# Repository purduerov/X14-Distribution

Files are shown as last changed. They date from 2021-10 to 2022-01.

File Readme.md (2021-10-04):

# Readme for X14-Distribution

Whenever you make a new part, download the datasheet and save it here _**and**_ with the part in the parts library

Always pull other people's changes before beginning to work
`git pull`

Be sure to push your changes after  working on them. Run:
1. `git add .` to add any files in this directory or a subdirectory
or `git add -u` to add any modified files
2. (Optional) `git clean -nX` to see what ignored files can be removed
	`git clean -fX` removes ignored files (Eagle backups)
3. `git commit -m "helpful commit message"` with a description of the work that you did
4. `git push` to push your work to github

Other helpful commands
* `git status` says information about modified and staged files
* `git log` shows the recent commits of the repository
* `git log filename.extension` show the recent commits for just that file
* `git checkout first-couple-letter-of-commit-id` lets you go back to a previous version
* `git checkout master` brings you back to the latest commit
* `git tag` lists the tags
* `git tag -a orderX -m "the version of the board placed for the X'th order"` tag a specific commit
* `git push --tags` needed to push tags to remote
* `git show orderX` show the commit log for the given tag
* `git checkout orderX` go back and interact with the files at the tagged commit

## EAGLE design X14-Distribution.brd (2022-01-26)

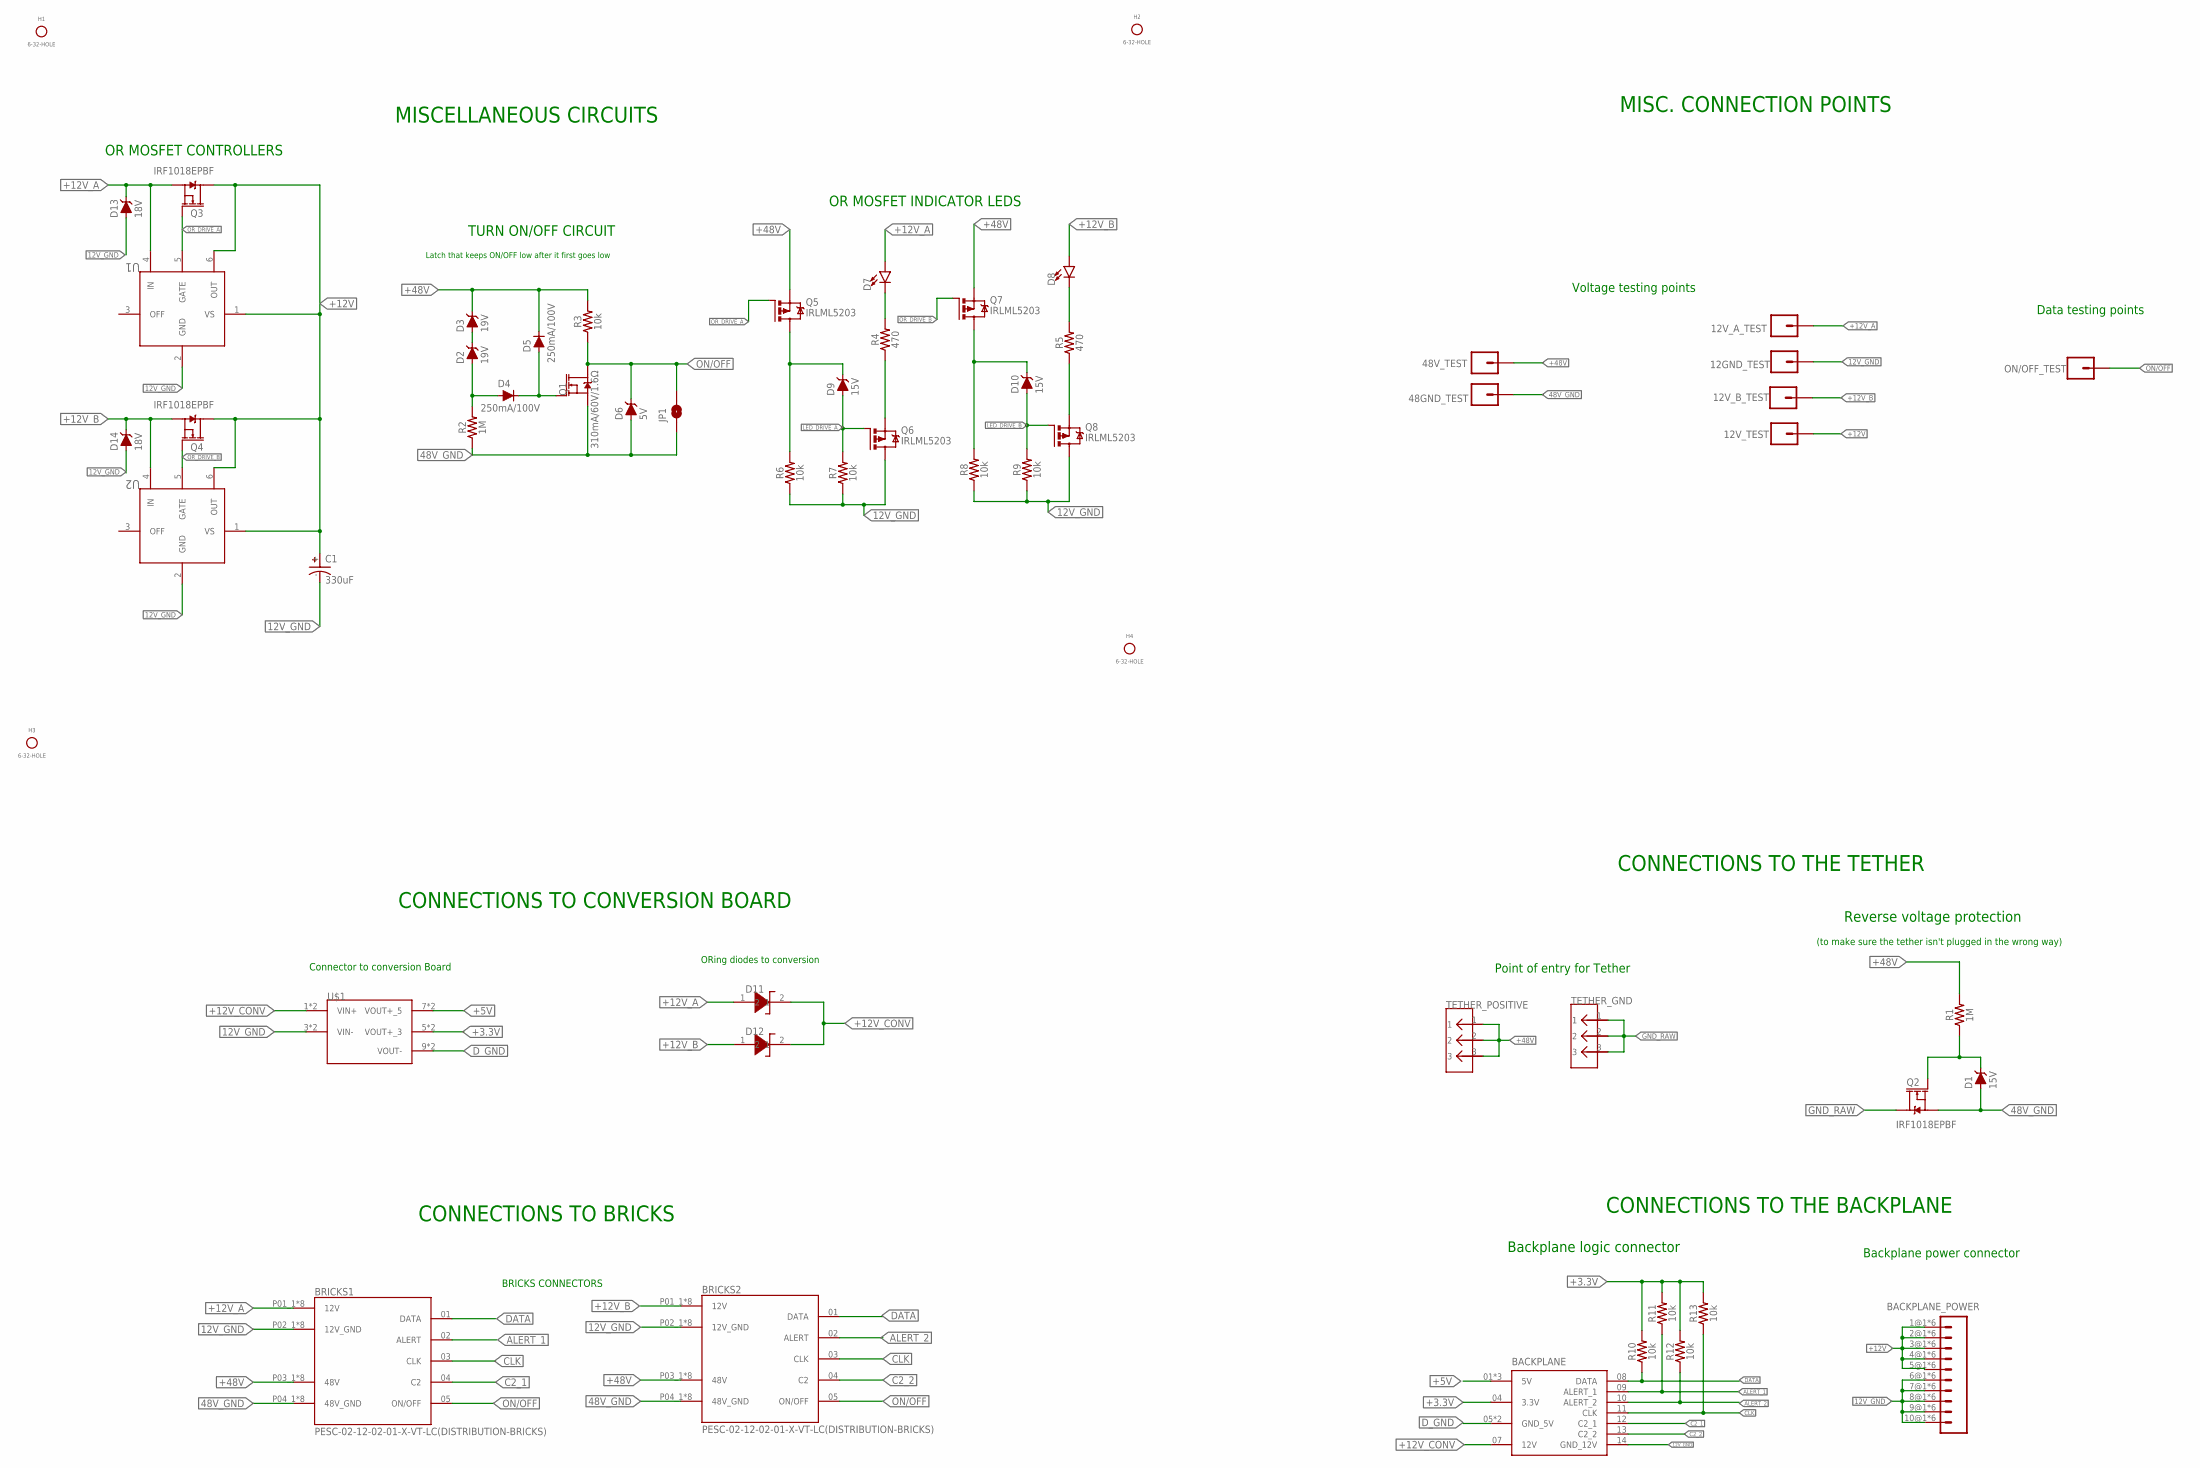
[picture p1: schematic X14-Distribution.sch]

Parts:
12GND_TEST, 12V_A_TEST, 12V_B_TEST, 12V_TEST, 48GND_TEST, 48V_TEST: CONN_01; 1X01
BACKPLANE: DISTRIBUTION-BACKPLANE; SAMTEC_IPL1-107-01-X-D-K(D-B)
BACKPLANE_POWER: MPPT-10-01-01-L-RA-SD
BRICKS1, BRICKS2: PESC-02-12-02-01-X-VT-LC(DISTRIBUTION-BRICKS); SAMTEC_PESC-02-12-02-01-X-VT-LC(D-B)
C1: 330uF; CAPAE1030X1050N
D1, D9, D10: 15V; SOD-323
D2, D3: 19V; SOD-323
D4, D5: 250mA/100V; SOD-323
D6: 5V; SOD-323
D7, D8: LED0603; LED-0603
D11, D12: DIODE-DO-214AC(SK34ATR)
D13, D14: 18V; PANASONIC_SMINI2-F5-B
H1, H2, H3, H4: 6-32-HOLE
JP1: JUMPER-SMT_2_NO_SILK; SMT-JUMPER_2_NO_SILK
ON/OFF_TEST: CONN_01; 1X01
Q1: 310mA/60V/1.6Ω; SOT323
Q2, Q3, Q4: IRF1018EPBF; TO263
Q5, Q6, Q7, Q8: IRLML5203; SOT23
R1, R2: 1M; 0603
R3, R6, R7, R8, R9, R10, R11, R12, R13: 10k; 0603
R4, R5: 470; 0603
TETHER_GND: 796636-3
TETHER_POSITIVE: 796636-3
U1, U2: DIST_OR_CONTROL_ALTMK06A-M; SOT-23-6
U$1: DISTRIBUTION-CONVERSION; TSW-105-05-G-S(D-C)

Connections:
12V_GND: 12GND_TEST.1, BACKPLANE.14 (GND_12V), BACKPLANE_POWER.6@1 (6), BACKPLANE_POWER.6@2 (6), BACKPLANE_POWER.6@3 (6), BACKPLANE_POWER.6@4 (6), BACKPLANE_POWER.6@5 (6), BACKPLANE_POWER.6@6 (6), BACKPLANE_POWER.7@1 (7), BACKPLANE_POWER.7@2 (7), BACKPLANE_POWER.7@3 (7), BACKPLANE_POWER.7@4 (7), BACKPLANE_POWER.7@5 (7), BACKPLANE_POWER.7@6 (7), BACKPLANE_POWER.8@1 (8), BACKPLANE_POWER.8@2 (8), BACKPLANE_POWER.8@3 (8), BACKPLANE_POWER.8@4 (8), BACKPLANE_POWER.8@5 (8), BACKPLANE_POWER.8@6 (8), BACKPLANE_POWER.9@1 (9), BACKPLANE_POWER.9@2 (9), BACKPLANE_POWER.9@3 (9), BACKPLANE_POWER.9@4 (9), BACKPLANE_POWER.9@5 (9), BACKPLANE_POWER.9@6 (9), BACKPLANE_POWER.10@1 (10), BACKPLANE_POWER.10@2 (10), BACKPLANE_POWER.10@3 (10), BACKPLANE_POWER.10@4 (10), BACKPLANE_POWER.10@5 (10), BACKPLANE_POWER.10@6 (10), BRICKS1.P02_1 (12V_GND), BRICKS1.P02_2 (12V_GND), BRICKS1.P02_3 (12V_GND), BRICKS1.P02_4 (12V_GND), BRICKS1.P02_5 (12V_GND), BRICKS1.P02_6 (12V_GND), BRICKS1.P02_7 (12V_GND), BRICKS1.P02_8 (12V_GND), BRICKS2.P02_1 (12V_GND), BRICKS2.P02_2 (12V_GND), BRICKS2.P02_3 (12V_GND), BRICKS2.P02_4 (12V_GND), BRICKS2.P02_5 (12V_GND), BRICKS2.P02_6 (12V_GND), BRICKS2.P02_7 (12V_GND), BRICKS2.P02_8 (12V_GND), C1.-, D13.A, D14.A, Q6.3 (D), Q8.3 (D), R6.1, R7.1, R8.1, R9.1, U1.2 (GND), U2.2 (GND), U$1.3 (VIN-), U$1.4 (VIN-)
48V_GND: 48GND_TEST.1, BRICKS1.P04_1 (48V_GND), BRICKS1.P04_2 (48V_GND), BRICKS1.P04_3 (48V_GND), BRICKS1.P04_4 (48V_GND), BRICKS1.P04_5 (48V_GND), BRICKS1.P04_6 (48V_GND), BRICKS1.P04_7 (48V_GND), BRICKS1.P04_8 (48V_GND), BRICKS2.P04_1 (48V_GND), BRICKS2.P04_2 (48V_GND), BRICKS2.P04_3 (48V_GND), BRICKS2.P04_4 (48V_GND), BRICKS2.P04_5 (48V_GND), BRICKS2.P04_6 (48V_GND), BRICKS2.P04_7 (48V_GND), BRICKS2.P04_8 (48V_GND), D1.A, D6.A, JP1.1, Q1.2 (S), Q2.2 (S), R2.1
+3.3V: BACKPLANE.04 (3.3V), R10.2, R11.2, R12.2, R13.2, U$1.5 (VOUT+_3), U$1.6 (VOUT+_3)
+5V: BACKPLANE.01 (5V), BACKPLANE.02 (5V), BACKPLANE.03 (5V), U$1.7 (VOUT+_5), U$1.8 (VOUT+_5)
+12V: 12V_TEST.1, BACKPLANE_POWER.1@1 (1), BACKPLANE_POWER.1@2 (1), BACKPLANE_POWER.1@3 (1), BACKPLANE_POWER.1@4 (1), BACKPLANE_POWER.1@5 (1), BACKPLANE_POWER.1@6 (1), BACKPLANE_POWER.2@1 (2), BACKPLANE_POWER.2@2 (2), BACKPLANE_POWER.2@3 (2), BACKPLANE_POWER.2@4 (2), BACKPLANE_POWER.2@5 (2), BACKPLANE_POWER.2@6 (2), BACKPLANE_POWER.3@1 (3), BACKPLANE_POWER.3@2 (3), BACKPLANE_POWER.3@3 (3), BACKPLANE_POWER.3@4 (3), BACKPLANE_POWER.3@5 (3), BACKPLANE_POWER.3@6 (3), BACKPLANE_POWER.4@1 (4), BACKPLANE_POWER.4@2 (4), BACKPLANE_POWER.4@3 (4), BACKPLANE_POWER.4@4 (4), BACKPLANE_POWER.4@5 (4), BACKPLANE_POWER.4@6 (4), BACKPLANE_POWER.5@1 (5), BACKPLANE_POWER.5@2 (5), BACKPLANE_POWER.5@3 (5), BACKPLANE_POWER.5@4 (5), BACKPLANE_POWER.5@5 (5), BACKPLANE_POWER.5@6 (5), C1.+, Q3.3 (D), Q4.3 (D), U1.1 (VS), U1.6 (OUT), U2.1 (VS), U2.6 (OUT)
+12V_A: 12V_A_TEST.1, BRICKS1.P01_1 (12V), BRICKS1.P01_2 (12V), BRICKS1.P01_3 (12V), BRICKS1.P01_4 (12V), BRICKS1.P01_5 (12V), BRICKS1.P01_6 (12V), BRICKS1.P01_7 (12V), BRICKS1.P01_8 (12V), D7.A, D11.1, D13.C, Q3.2 (S), U1.4 (IN)
+12V_B: 12V_B_TEST.1, BRICKS2.P01_1 (12V), BRICKS2.P01_2 (12V), BRICKS2.P01_3 (12V), BRICKS2.P01_4 (12V), BRICKS2.P01_5 (12V), BRICKS2.P01_6 (12V), BRICKS2.P01_7 (12V), BRICKS2.P01_8 (12V), D8.A, D12.1, D14.C, Q4.2 (S), U2.4 (IN)
+12V_CONV: BACKPLANE.07 (12V), D11.2, D12.2, U$1.1 (VIN+), U$1.2 (VIN+)
+48V: 48V_TEST.1, BRICKS1.P03_1 (48V), BRICKS1.P03_2 (48V), BRICKS1.P03_3 (48V), BRICKS1.P03_4 (48V), BRICKS1.P03_5 (48V), BRICKS1.P03_6 (48V), BRICKS1.P03_7 (48V), BRICKS1.P03_8 (48V), BRICKS2.P03_1 (48V), BRICKS2.P03_2 (48V), BRICKS2.P03_3 (48V), BRICKS2.P03_4 (48V), BRICKS2.P03_5 (48V), BRICKS2.P03_6 (48V), BRICKS2.P03_7 (48V), BRICKS2.P03_8 (48V), D3.C, D5.C, Q5.2 (S), Q7.2 (S), R1.2, R3.2, TETHER_POSITIVE.1, TETHER_POSITIVE.2, TETHER_POSITIVE.3
ALERT_1: BACKPLANE.09 (ALERT_1), BRICKS1.02 (ALERT), R11.1
ALERT_2: BACKPLANE.10 (ALERT_2), BRICKS2.02 (ALERT), R12.1
C2_1: BACKPLANE.12 (C2_1), BRICKS1.04 (C2)
C2_2: BACKPLANE.13 (C2_2), BRICKS2.04 (C2)
CLK: BACKPLANE.11 (CLK), BRICKS1.03 (CLK), BRICKS2.03 (CLK), R13.1
DATA: BACKPLANE.08 (DATA), BRICKS1.01 (DATA), BRICKS2.01 (DATA), R10.1
D_GND: BACKPLANE.05 (GND_5V), BACKPLANE.06 (GND_5V), U$1.9 (VOUT-), U$1.10 (VOUT-)
GND_RAW: Q2.3 (D), TETHER_GND.1, TETHER_GND.2, TETHER_GND.3
LED_DRIVE_A: D9.A, Q6.1 (G), R7.2
LED_DRIVE_B: D10.A, Q8.1 (G), R9.2
unnamed: D1.C, Q2.1 (G), R1.1
unnamed: D4.C, D5.A, Q1.1 (G)
unnamed: Q6.2 (S), R4.1
unnamed: D2.C, D3.A
unnamed: D9.C, Q5.3 (D), R6.2
unnamed: D2.A, D4.A, R2.2
unnamed: Q8.2 (S), R5.1
unnamed: D10.C, Q7.3 (D), R8.2
unnamed: D7.C, R4.2
unnamed: D8.C, R5.2
ON/OFF: BRICKS1.05 (ON/OFF), BRICKS2.05 (ON/OFF), D6.C, JP1.2, ON/OFF_TEST.1, Q1.3 (D), R3.1
OR_DRIVE_A: Q3.1 (G), Q5.1 (G), U1.5 (GATE)
OR_DRIVE_B: Q4.1 (G), Q7.1 (G), U2.5 (GATE)

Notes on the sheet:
OR MOSFET INDICATOR LEDS
Backplane logic connector
OR MOSFET CONTROLLERS
ORing diodes to conversion
Reverse voltage protection
TURN ON/OFF CIRCUIT
Latch that keeps ON/OFF low after it first goes low
BRICKS CONNECTORS
Connector to conversion Board
Voltage testing points
CONNECTIONS TO CONVERSION BOARD
CONNECTIONS TO BRICKS
MISC. CONNECTION POINTS
CONNECTIONS TO THE TETHER
Backplane power connector
Data testing points
Point of entry for Tether
CONNECTIONS TO THE BACKPLANE
(to make sure the tether isn't plugged in the wrong way)
MISCELLANEOUS CIRCUITS

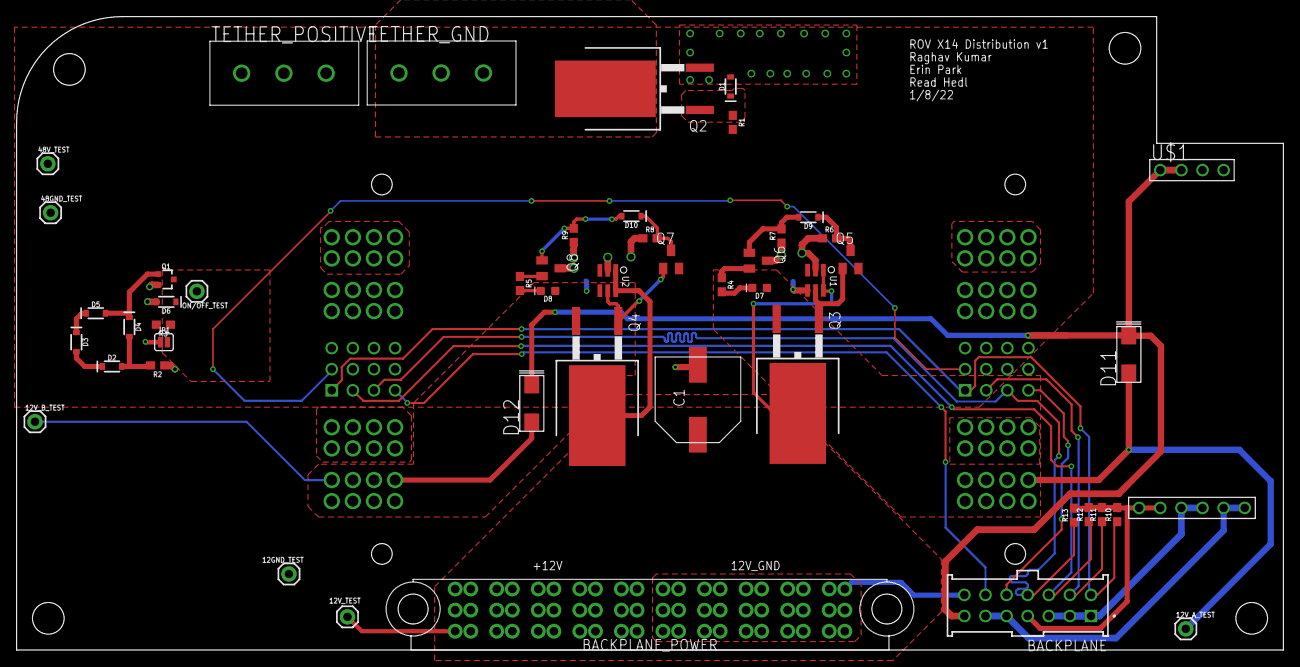
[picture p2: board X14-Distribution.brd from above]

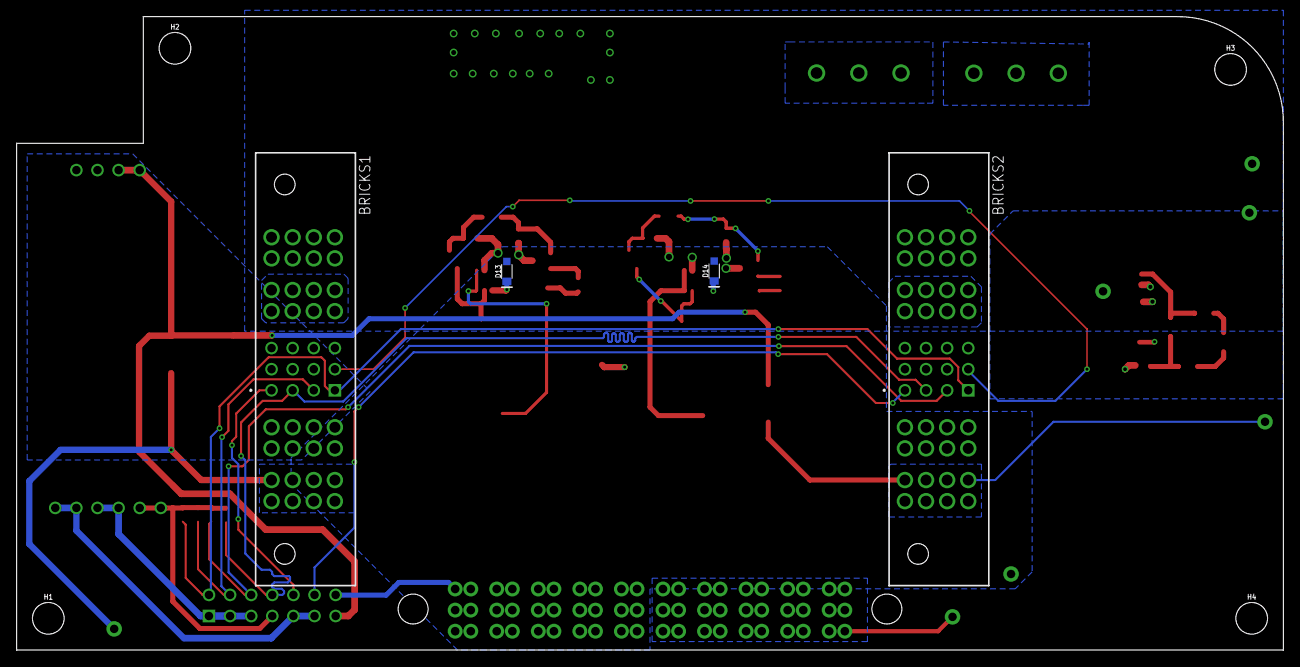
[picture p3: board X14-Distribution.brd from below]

Board: 2 copper layers, 152.4 x 76.2 mm, 57 parts (8 on the bottom side), 32 nets.

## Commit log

2021-09-25 added schematic file with only frame to the repository
    [X14-Distribution.sch]
2021-10-02 Added the Reverse voltage blocker from the tether, OR MOSFET controller, and ON/OFF signal for Bricks
    [X14-Distribution.sch]
2021-10-04 Added the schottky diode ORing for the conversion board
    [X14-Distribution.sch]
2021-10-05 Added the test points, points of entry for different voltage levels, and power connection to the Backplane
    [X14-Distribution.sch]
2021-10-13 Added conversion board connector
    [X14-Distribution.sch]
2021-10-16 Added descriptive green text and some connectors
    [X14-Distribution.sch]
2021-10-20 Added connectors to Bricks and some more extra green explanation text
    [X14-Distribution.sch]
2021-10-21 Added more green explanatory text, and spread out the schematic to make it look better
    [X14-Distribution.sch]
2021-10-21 Made a little spacing change
    [X14-Distribution.sch]
2021-10-28 Changed footprint of schottky diode
    [X14-Distribution.sch]
2021-10-30 Changed ORing LED MOSFETs to p-channel TSM2309CX RFG
    [X14-Distribution.sch]
2021-10-30 Changed the p-mosfets to be oriented the right way
    [X14-Distribution.sch]
2021-10-30 Fixed some junction connection errors
    [X14-Distribution.sch]
2021-11-03 Changed the Backplane Logic connector
    [X14-Distribution.sch]
2021-11-03 Added board file
    [X14-Distribution.brd]
2021-11-10 added board dimensions
    [X14-Distribution.brd]
2021-11-20 Made some changes for the board
    [X14-Distribution.brd, X14-Distribution.sch]
2021-11-24 Made some changes to board and added 18V zener diodes from 12V_A and B to ground
    [X14-Distribution.brd, X14-Distribution.sch]
2021-11-29 didn't change anything
    [X14-Distribution.brd]
2021-12-01 Made some more changes to the board
    [X14-Distribution.brd, X14-Distribution.sch]
2021-12-01 Made changes to the board
    [X14-Distribution.brd]
2021-12-01 made more board changes
    [X14-Distribution.brd]
2021-12-02 Changed a lot of stuff on the board
    [X14-Distribution.brd]
2021-12-02 More board stuff
    [X14-Distribution.brd]
2021-12-02 Made more changes to the board
    [X14-Distribution.brd]
2021-12-04 Moved the ON/OFF circuit
    [X14-Distribution.brd]
2021-12-04 made some more changes
    [X14-Distribution.brd]
2021-12-04 Corrected a wire on the board
    [X14-Distribution.brd]
2021-12-04 Chagned some wires to make it fit DRC
    [X14-Distribution.brd]
2021-12-04 Mad e more changes
    [X14-Distribution.brd]
2021-12-04 Maybe done?
    [X14-Distribution.brd]
2021-12-08 moved on/off circuit
    [X14-Distribution.brd]
2021-12-11 Length-matched the DATA and CLK lines
    [X14-Distribution.brd, X14-Distribution.sch]
2021-12-11 Made a few more changes to the same board
    [X14-Distribution.brd]
2021-12-11 Finished all design review changes, except bricks connector
    [X14-Distribution.brd]
2021-12-11 Made changes according to Grant's notes
    [X14-Distribution.brd]
2021-12-11 Changed curves back to zigzagy thingys
    [X14-Distribution.brd]
2021-12-21 All changes except for bricks outlines
    [X14-Distribution.brd]
2021-12-25 Made some changes
    [X14-Distribution.brd]
2021-12-30 Added Bricks outline
    [X14-Distribution.brd, X14-Distribution.sch]
2021-12-30 added brick outline. Fixed a git error
    [X14-Distribution.brd, X14-Distribution.sch]
2022-01-01 Added the brick outline footprint
    [X14-Distribution.brd, X14-Distribution.sch]
2022-01-01 Fixed the DRC errors
    [X14-Distribution.brd]
2022-01-02 Changed the reverse voltage circuit to be horizontal
    [X14-Distribution.brd]
2022-01-02 Small change
    [X14-Distribution.brd]
2022-01-02 Some more changes
    [X14-Distribution.brd]
2022-01-07 added silkscreen, moved testpoints
    [X14-Distribution.brd]

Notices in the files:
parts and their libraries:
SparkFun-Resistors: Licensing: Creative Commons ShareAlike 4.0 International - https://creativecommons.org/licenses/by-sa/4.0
